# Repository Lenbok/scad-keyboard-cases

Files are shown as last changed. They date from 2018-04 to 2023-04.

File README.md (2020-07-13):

# OpenSCAD Mechanical Keyboard Cases

This repository uses OpenSCAD to make 3D-printable keyboard
cases. Initially this was simple modifications to an existing case for
the [Redox](https://github.com/mattdibi/redox-keyboard) handwire
keyboard, but now also provides the possibility to make a new case
generated in OpenSCAD from scratch.

When cloning, you need to make sure you get the submodules, e.g.:

    git clone --recurse-submodules https://github.com/Lenbok/scad-keyboard-cases.git

## Modified Version Of The Redox Case

Have a look in [redox-rev0-mod](redox-rev0-mod) for my modification of
the original handwire Redox case.

## Keyboard Cases From Scratch

I then wanted to design a new case for the Redox that was inspired both
by the Redox Rev1 case and the Iris, and I thought it would be nice to
start with the layout from the [Keyboard Layout
Editor](http://www.keyboard-layout-editor.com/) JSON file (in this way
it could be extended to other keyboards). Existing tools I had found for
going from KLE JSON to OpenSCAD didn't work for split keyboards where
some keys are rotated, so an updated tool is provided here that seems to
work on the split keyboards I have tried.

Examples: [Redox](redox-rev0b) and [Corne](crkbd) keyboards.

If you have another KLE JSON file you want to convert, run the included
`jsonPositions.py` which spits out the key layout to a minimal OpenSCAD
data structure along with some data access functions. E.g:

    python3 jsonPositions.py -v redox_layout <redox-rev0b/redox-layout.json >redox-rev0b/redox-layout.scad

Where `-v redox_layout` designates the OpenSCAD variable name used to
contain the layout data in the generated file.  Then make a top level
OpenSCAD that includes this along with `keyboard_case.scad`, e.g.:

    include <redox-rev0b/redox-layout.scad>
    include <keyboard_case.scad>

Then to make a case, you mostly just need to define a polygon describing the
outer boundary of your desired case, a set of points for where to put
case screw holes, and optional positions for tenting supports, and call
the `top_case` and/or `bottom_case` modules. 

See some of the cases here for examples:

Redox:

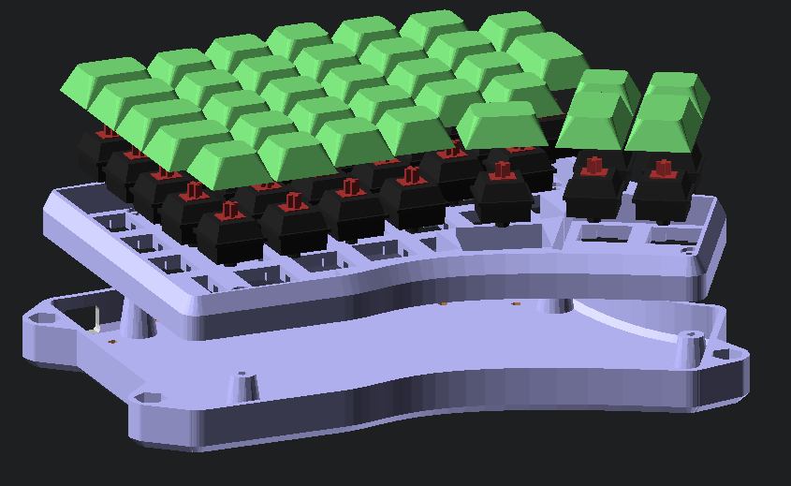
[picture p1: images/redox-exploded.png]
redox exploded


CRKBD (main shell is top half):

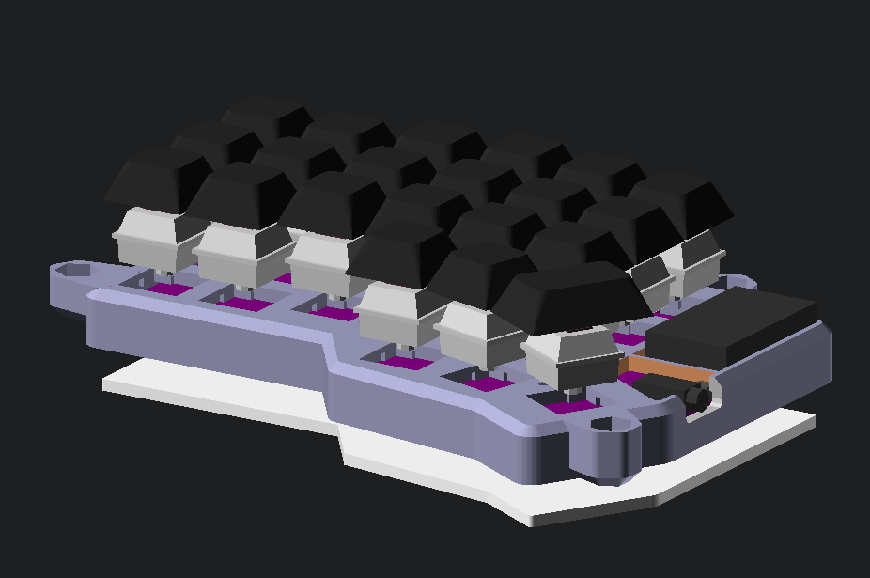
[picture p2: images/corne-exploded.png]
crkbd


CRKBD "alternate" (hi-profile, main shell is lower half):

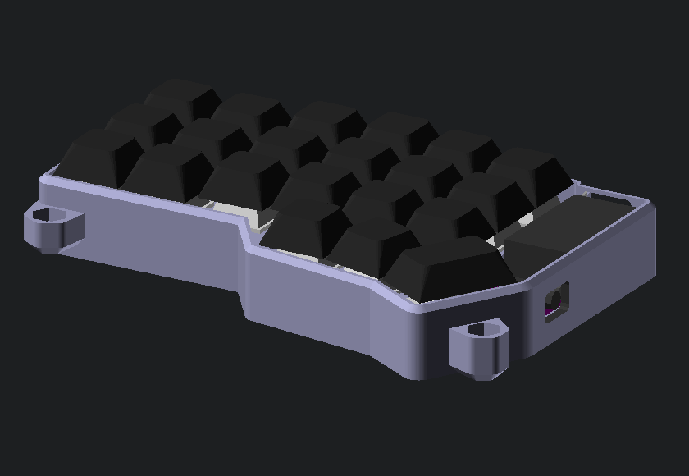
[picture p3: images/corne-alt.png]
crkbd alternate


CRKBD "minimal" (here using bottom mount mcu and reset for low profile):

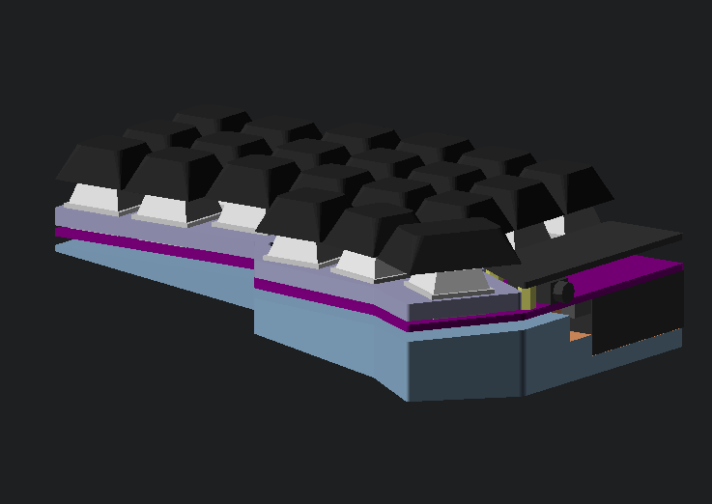
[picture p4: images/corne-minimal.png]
crkbd minimal


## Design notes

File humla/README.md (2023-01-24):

## Humla keyboard cases

In this folder are a couple of different cases for the
[Humla](https://github.com/jimmerricks/humla) keyboard.

### Simple bumper

Just a straight bumper-style case:

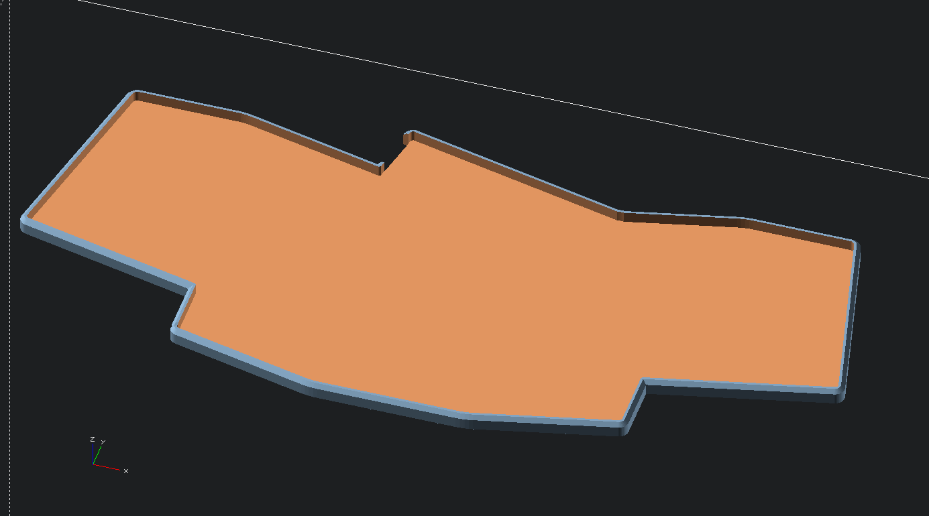
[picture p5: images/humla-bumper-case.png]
humla bumper


At the moment, the case does not attach with screws, it just fits snugly.

### "Laptop Adaptor" case

Since one use case when building this keyboard was as an comfortable
alternative to the keyboard built-in to my work laptop (a HP ZBook Firefly), this
case is an adaptor that lets the humla sit over the top of the laptop
keyboard. Recesses corresponding to the laptop keys keep the humla positioned.

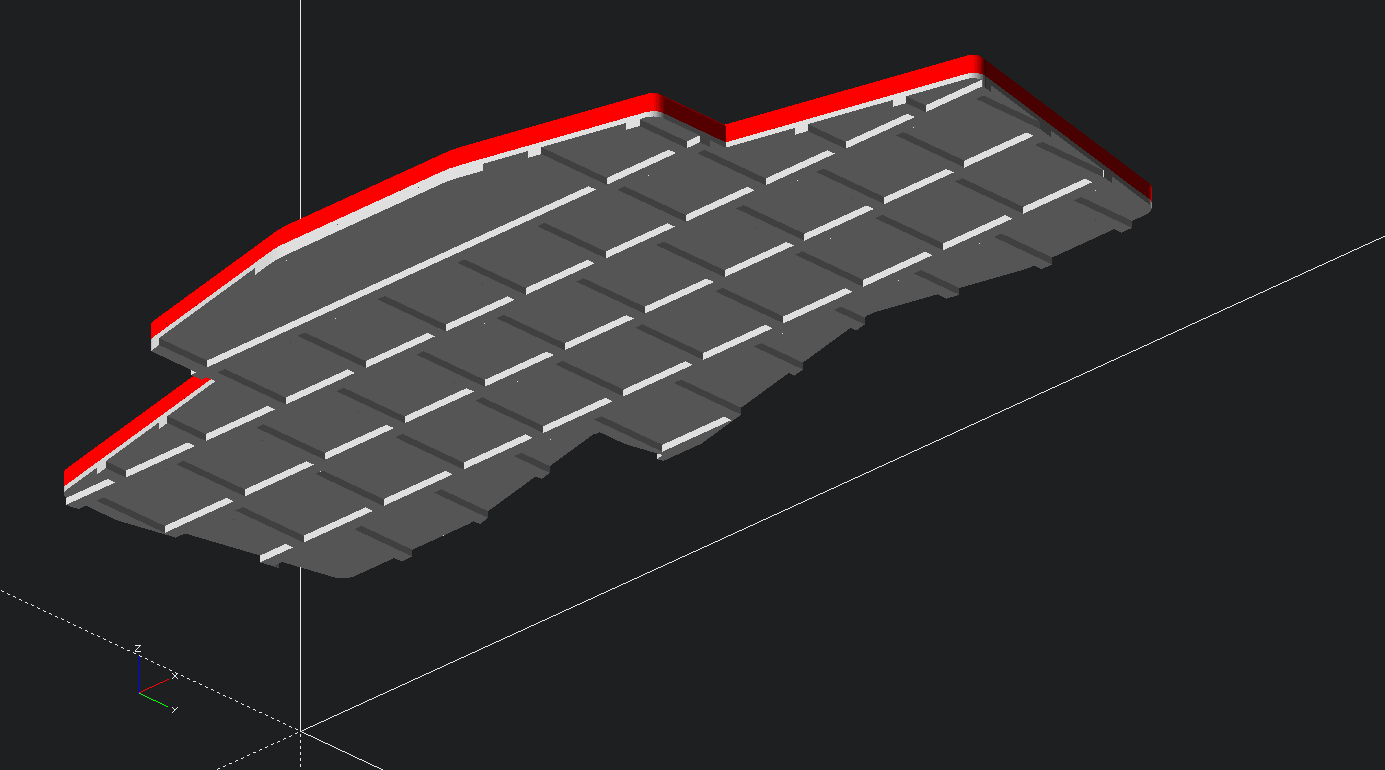
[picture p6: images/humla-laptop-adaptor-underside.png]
humla laptop adaptor case


To make this case, print one adaptor plate and one bumper plate and glue them
together.

It would be easy to alter this for a different laptop by creating a KLE layout
containing the positions and sizes of your laptop keyboard, and running the
converter in this repo to convert that into the OpenSCAD data structure
required.

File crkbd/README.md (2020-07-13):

## CRKBD keyboard cases from scratch

In this folder are a couple of different cases for the
[Corne](https://github.com/foostan/crkbd) keyboard.

### Default case (AKA first version)

This has a top plate with tenting supports attached. The bottom plate
could be 3D printed in transparent plastic so that underglow shows
through (it should also be compatible with the laser cut acrylic bottom
plate).

crkbd exploded

The top part has a couple of struts across where the OLED screen goes
that are purely to assist with keeping the edge attached during
printing, and these should be cut out after printing. The outermost
tenting mounts are raised compared to the inner ones, this is to allow
the outer sides to sit closer to the desk.

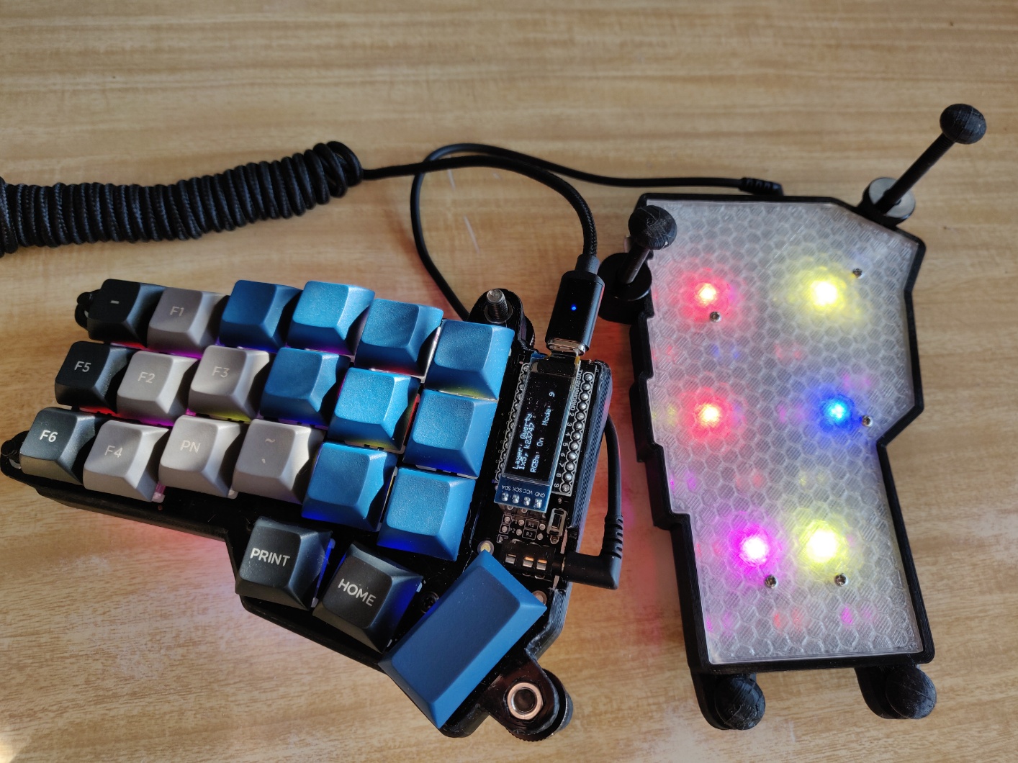
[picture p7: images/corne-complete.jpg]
corne complete


I've also designed a simple carrier that each half of the keyboard slots
into, and which has a wee compartment into which you can put the TRRS
cable and tenting legs during transport.

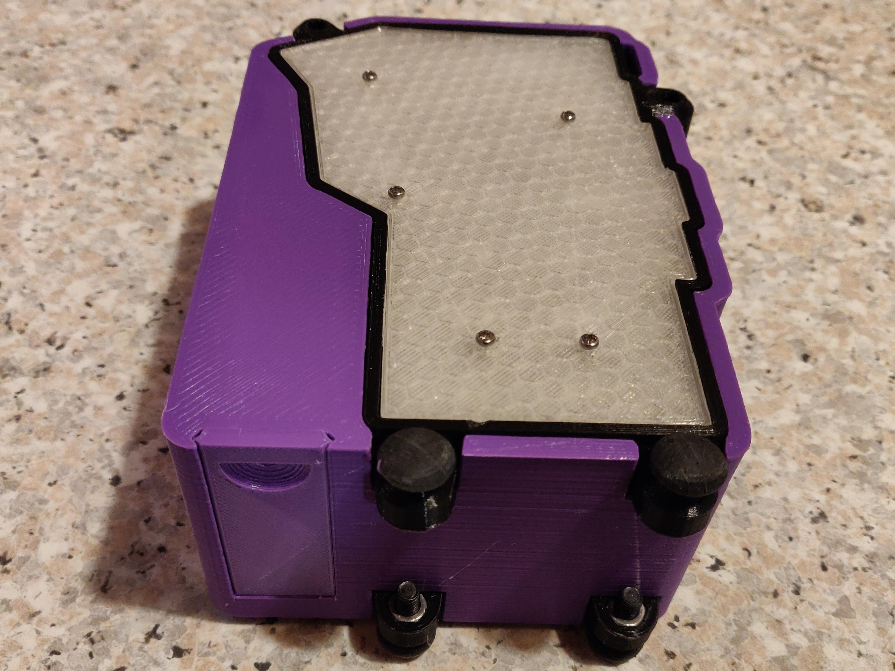
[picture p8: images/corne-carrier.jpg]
corne carrier


### "Alternate" case

This version of the case has a simple printed top plate (essentially as
thick as possible for strength - you may need to clip diode legs etc),
and the bottom half contains the tenting etc. This version is "high
profile" where the sides come up to the bottom of the keycaps:

crkbd alternate

The tenting positions are differently arranged, but you can use the
definitions from the default case if you prefer those.

If you want this case to be compatible with RGB underglow lighting, it's
best to print the first few mm in transparent filament before swapping
to the color you want for the bulk of the case.

Mine is using a top mounted
[nRFMicro](https://github.com/joric/nrfmicro) for bluetooth, and has a
separate LiPo battery bay.

Here are the default and alternate cases:

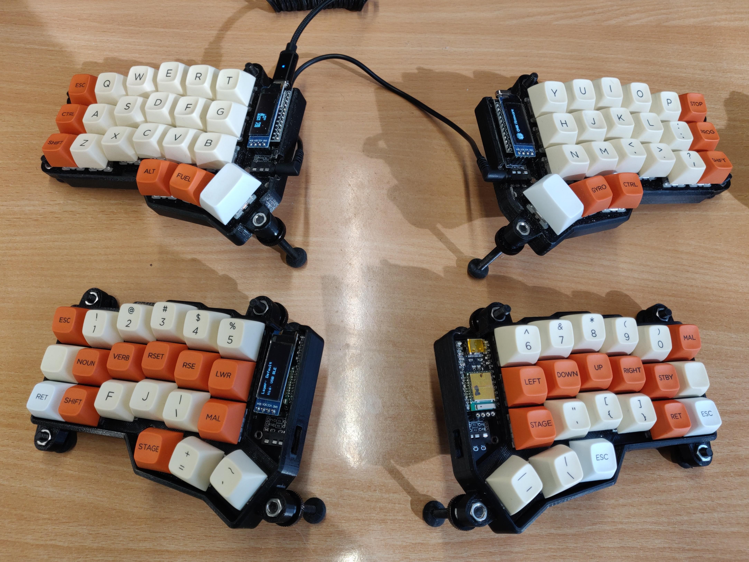
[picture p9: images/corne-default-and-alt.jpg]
crkbd default and alt


### "Minimal" case

This version of the case has the same simple top plate as the alternate
case, and the bottom is pretty much a wedge shape so we have the minimal
footprint. You can configure whether you want the MCU and/or the reset
switch mounted under the PCB (this allows the OLED to sit close to the
PCB).

crkbd minimal

Mine is using a bottom mounted
[nRFMicro](https://github.com/joric/nrfmicro) which also straddles a
small LiPo, making it a nice compact bluetooth keyboard.

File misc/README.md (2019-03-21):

# Misc Supporting Files

The tenting solution I've been using has been based around M5 coach
bolts, and I've been using 3D printed molds to cast
[Oogoo](https://www.instructables.com/id/How-To-Make-Your-Own-Sugru-Substitute/)
around the heads of the bolts to give them rubber feet.

Rubber Feet Enabled Bolts

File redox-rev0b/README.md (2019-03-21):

## Redox Keyboard Case From Scratch

I wanted to design a new case for the Redox that was inspired both
by the Redox Rev1 case and the Iris, and I thought it would be nice to
start with the layout from the [Keyboard Layout
Editor](http://www.keyboard-layout-editor.com/) JSON file (in this way
it could be extended to other keyboards). Existing tools I had found for
going from KLE JSON to OpenSCAD didn't work for split keyboards where
some keys are rotated, so an updated tool is provided here that seems to
work on the split keyboards I have tried.

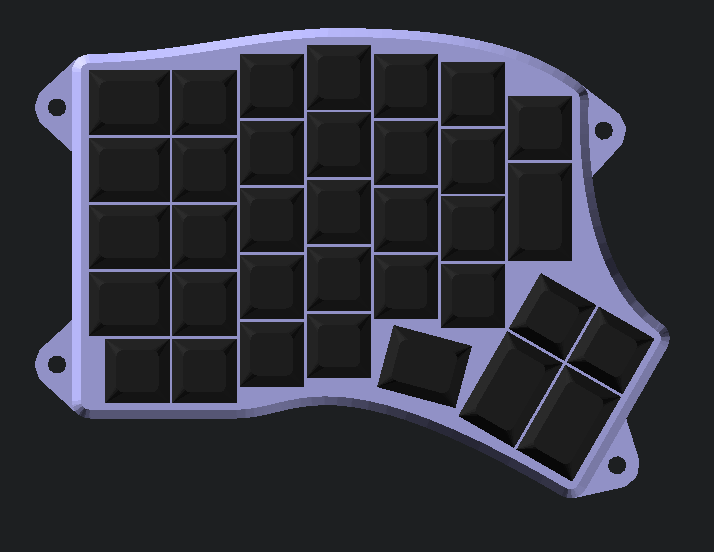
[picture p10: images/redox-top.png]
redox-top


redox-exploded

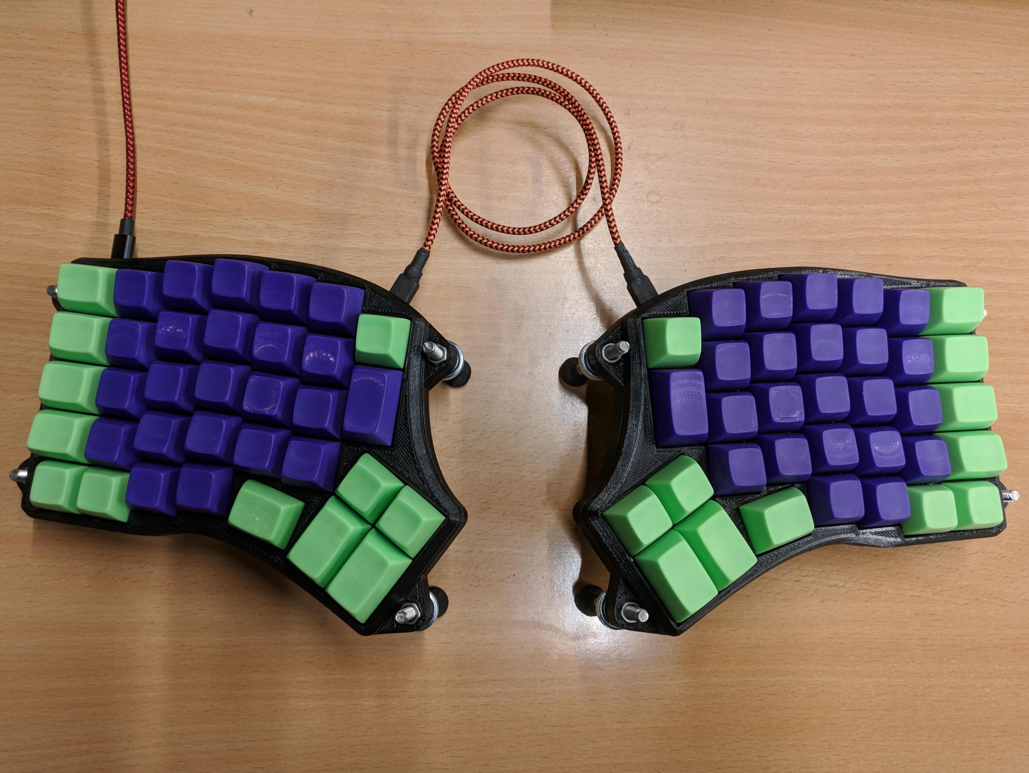
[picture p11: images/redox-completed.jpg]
redox-completed

[album here](https://imgur.com/a/eEi0gJ1)

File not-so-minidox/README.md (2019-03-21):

## Not-so-minidox Keyboard Case From Scratch

This is initial work on a case for the
[Not-so-minidox](https://www.reddit.com/r/MechanicalKeyboards/comments/8j8k1i/the_not_so_minidox_handwire/)
keyboard, but I've since decided to build a Corne keyboard instead.

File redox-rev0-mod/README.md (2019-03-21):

# A modified case for the Redox keyboard

The [Redox](https://github.com/mattdibi/redox-keyboard) keyboard is a DIY mechanical 
keyboard by MattDB. It is sort of a cross between an 
[Iris](https://keeb.io/products/iris-keyboard-split-ergonomic-keyboard) and an 
[Ergodox](https://ergodox-ez.com/).

This repository uses OpenSCAD to make some modifications to the original STL to add
tenting etc.

This was my first modification of the original handwire redox case. Load the
`redox-body-mod.scad` into OpenSCAD, make any changes, and render the
modified STL.

This one has been built by a few people, e.g: [by me](https://imgur.com/a/DzFYMhc), 
and [a coworker](https://www.thingiverse.com/make:486818)

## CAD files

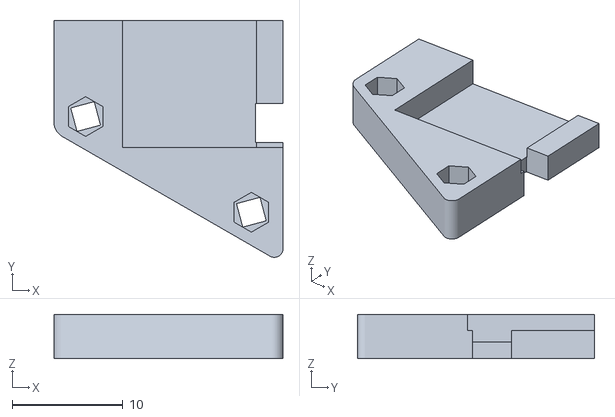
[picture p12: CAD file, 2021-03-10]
crkbd/stls/crkbd-case-encoder-mount.stl
20.7 x 21.4 x 4.00

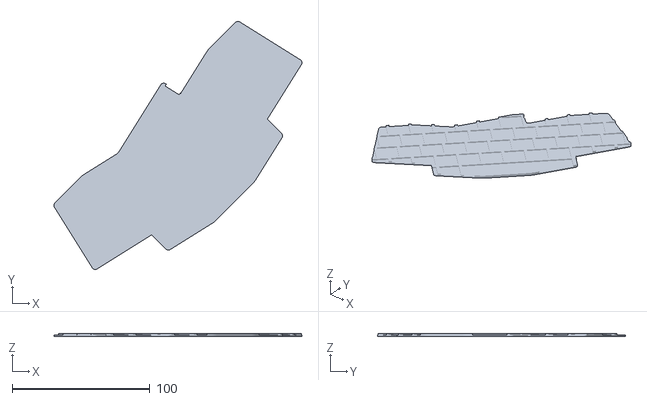
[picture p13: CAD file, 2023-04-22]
humla/stl/humla-laptop-adaptor-case-bottom.stl
180.2 x 180.2 x 2.29

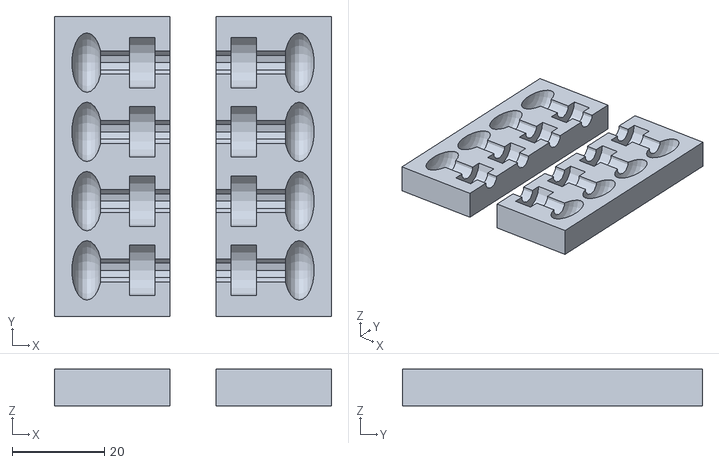
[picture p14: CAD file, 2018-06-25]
misc/stls/Foot_Mold.stl
60.0 x 65.0 x 8.00

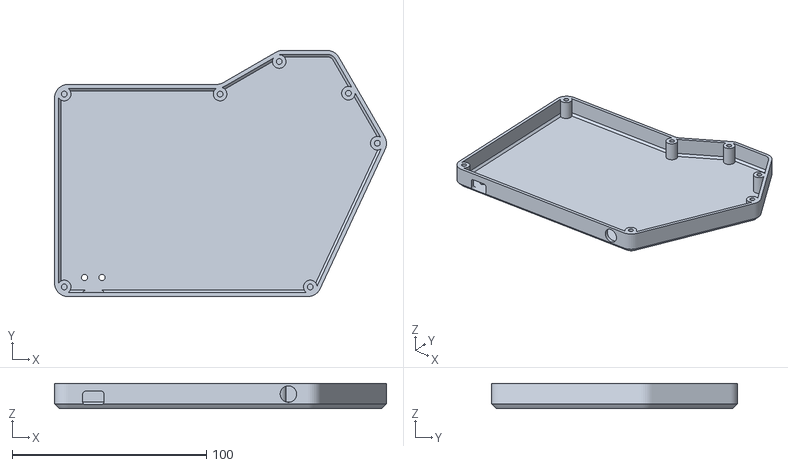
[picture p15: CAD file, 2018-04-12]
redox-rev0-mod/orig/BottomR.stl
171.1 x 126.9 x 13.0

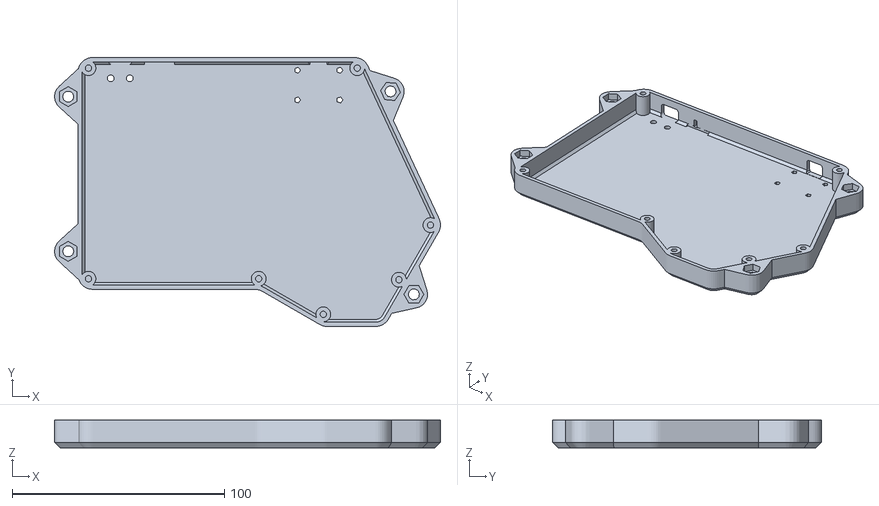
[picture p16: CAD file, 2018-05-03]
redox-rev0-mod/stls/Tented_BottomL.stl
182.1 x 126.9 x 13.0

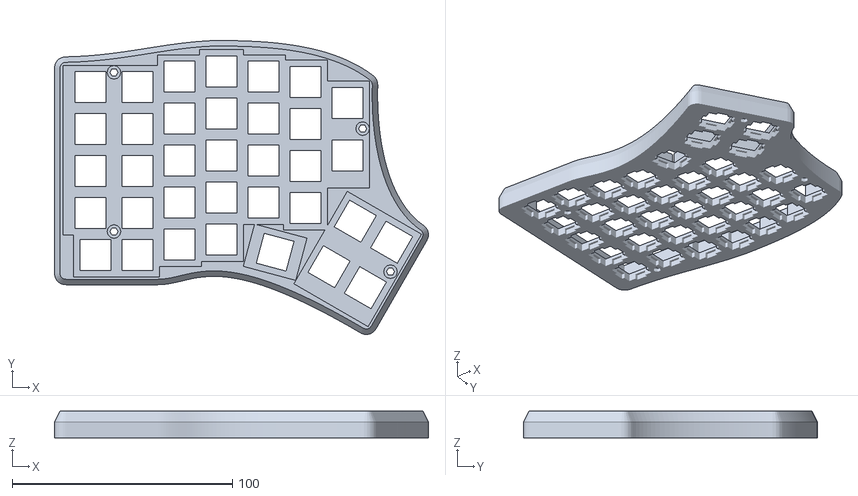
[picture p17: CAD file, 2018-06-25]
redox-rev0b/stls/redox-rev0b-hightop.stl
169.6 x 133.4 x 12.2

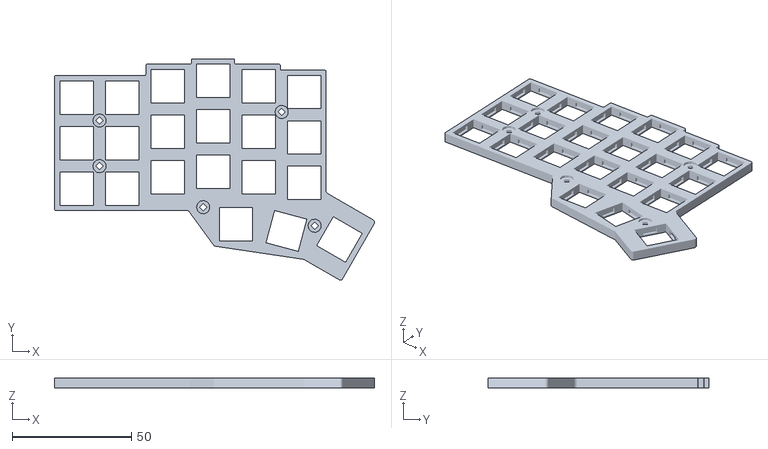
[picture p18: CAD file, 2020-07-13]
crkbd/stls/crkbd-case-minimal-top.stl
134.1 x 92.8 x 4.00

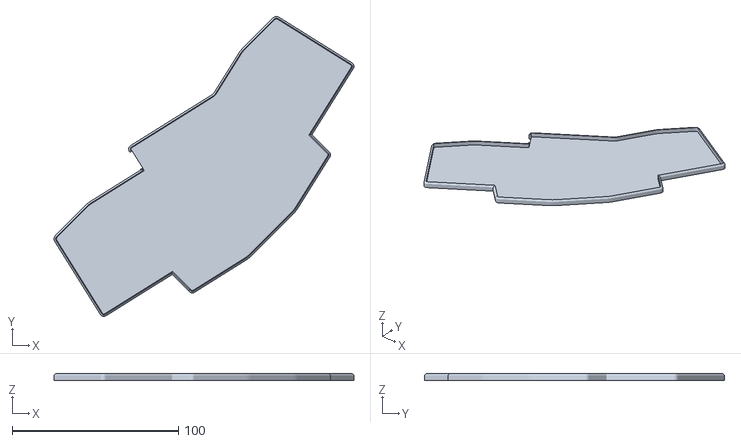
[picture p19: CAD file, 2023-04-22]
humla/stl/humla-bumper-case.stl
180.2 x 180.2 x 4.00

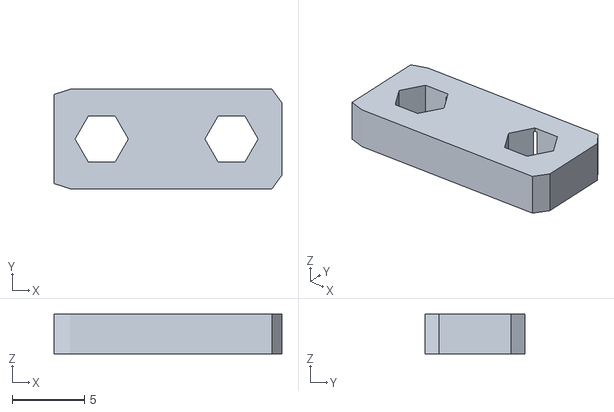
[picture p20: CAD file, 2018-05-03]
misc/stls/Micro_USB_Spacer.stl
15.8 x 6.90 x 2.75

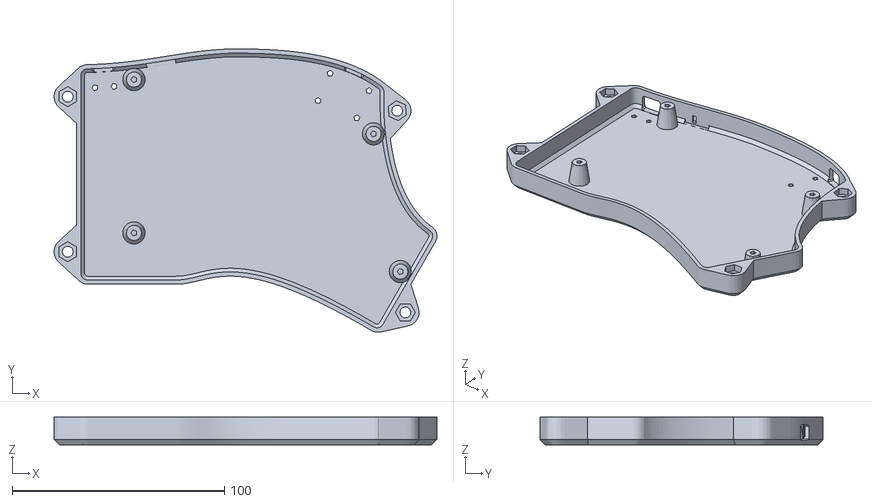
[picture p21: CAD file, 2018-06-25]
redox-rev0b/stls/redox-rev0b-bottom.stl
180.3 x 133.4 x 13.0

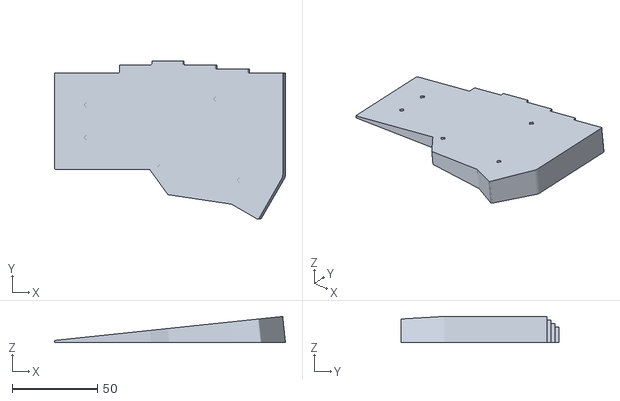
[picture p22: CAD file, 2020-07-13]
crkbd/stls/crkbd-case-minimal-bottom.stl
135.5 x 92.8 x 15.3

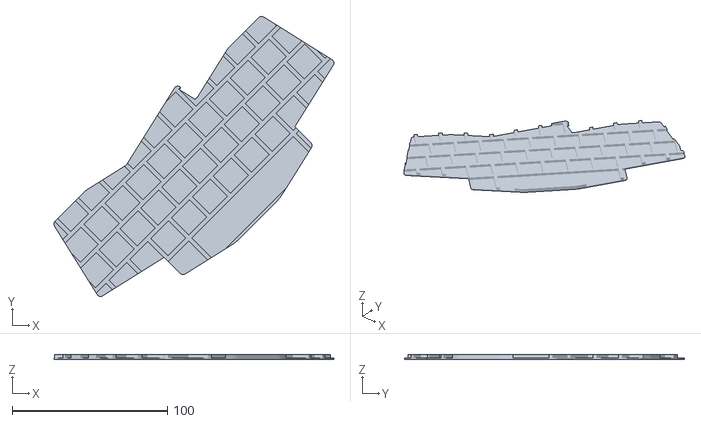
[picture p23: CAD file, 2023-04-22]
humla/stl/humla-macbook-adaptor-case-bottom.stl
180.2 x 180.2 x 2.99

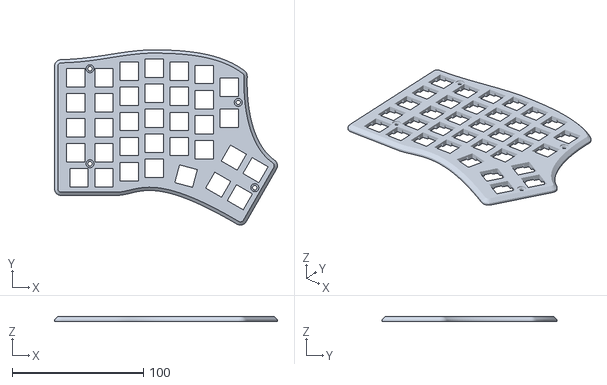
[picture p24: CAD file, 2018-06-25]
redox-rev0b/stls/redox-rev0b-lowtop.stl
169.6 x 133.4 x 4.00

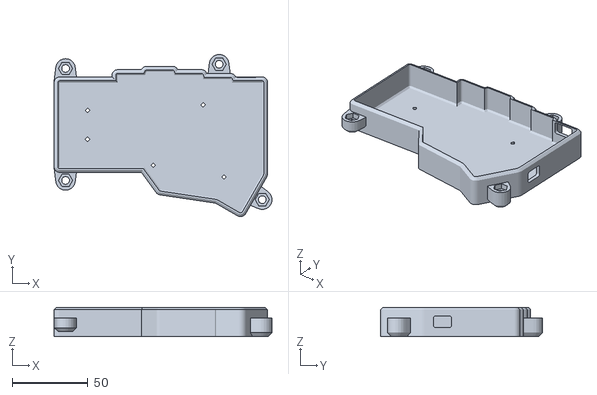
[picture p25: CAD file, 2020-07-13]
crkbd/stls/crkbd-case-alt-bottom.stl
144.0 x 107.1 x 19.2

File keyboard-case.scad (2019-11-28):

unit = 19.05;            // Unit size of spacing between keys

cherry_plate_width = 14; // Width of hole in plate for key insertion. Adjust if needed

plate_thickness = 4;   // Fairly thick for strength, ideally print this section with high infill
top_case_raised_height = 7.2 + 1; // Distance between plate and bottom of keycap plus a little extra, for raised top case
bottom_case_height = 13;  // Enough room to house electonics
wall_thickness = 2;     // Sides and bottom of case
depth_offset = 0;       // How much of side wall to include below top plate

// Case screw sizes
standoff_rad = 7 / 2;
screw_rad = 3.2 / 2;
screw_head_rad = 6 / 2;
screw_length = 8;
bottom_screws = false; // Default is to screw down from the top

themes = [
    //    case,    keycap, keyswitch,  keystem
    ["#101010", "#130044", "#222222", "#aa3333"],
    ["#180054", "#73d373", "#222222", "#aa3333"],
    ["#bbbbff", "#73d373", "#222222", "#aa3333"],
    ["#9999bb", "#252525", "#cccccc", "#553333"],
    ];
theme = 3;
case_color = themes[theme].x;
keycap_color = themes[theme].y;
keyswitch_color = themes[theme].z;
keystem_color = themes[theme][3];

// Create a hole where a switch can be inserted. The top of the hole is at 0
cherry_clip_recess_z = 1.3; // How far below the top the recess begins
cherry_clip_recess_width = 6; // How much of the side is taken up by the recess
cherry_clip_recess_depth = 1.0; // How far in does the clip go
cherry_clip_recess_height = 4.0; // How far down clip recess go
module switch_hole(size, depth = 5) {
    translate([0, 0, -depth]) {
        linear_extrude(height = depth + 0.01, center = false, convexity = 3)
            square([cherry_plate_width, cherry_plate_width], center = true);
        translate([0, 0, depth - cherry_clip_recess_z - cherry_clip_recess_height]) linear_extrude(height = cherry_clip_recess_height, center = false, convexity = 3)
            for (r = [0, 90])
                rotate([0, 0, r])
                    square([cherry_plate_width + 2 * cherry_clip_recess_depth, cherry_clip_recess_width], center = true);
    }
}

// A keyswitch for preview purposes
cherry_switch_width = 14;
cherry_switch_depth = 5.2;
module cherry_keyswitch() {
    color(keystem_color) translate([0, 0, 5]) {
        translate([0, 0, 0.5]) cube([7, 5.7, 1], center = true);
        translate([0, 0, 1 + 1.8])
            for (r = [0, 90])
                rotate([0, 0, r])
                cube([4.0, 1.2, 3.6], center = true);
    }
    color(keyswitch_color) {
        hull() {
            translate([0, 0, 0.99]) linear_extrude(height = 0.01, center = false, convexity = 3) 
                square([14, 14], center = true);
            translate([0, 0, 5.6]) linear_extrude(height = 0.01, center = false, convexity = 3) 
                square([11, 11], center = true);
        }
        translate([0, 0, 0.5]) cube([15.6, 15.6, 1], center = true);
        translate([0, 0, -8.3]) cylinder(r = 3.8 / 2, h = 5, $fn = 8);
        hull() {
            linear_extrude(height = 0.01, center = false, convexity = 3) 
                square([cherry_switch_width, cherry_switch_width], center = true);
            translate([0, 0, -cherry_switch_depth]) linear_extrude(height = 0.01, center = false, convexity = 3) 
                square([cherry_switch_width-0.5, cherry_switch_width-0.5], center = true);
        }
    }
}

// Something roughly DSA-ish for preview purposes
keycap_depth_offset = 7.2;  // Distance from bottom of keycap to top of plate.
module simple_keycap(size) {
    color(keycap_color) translate([0, 0, keycap_depth_offset]) hull() {
        linear_extrude(height = 0.01, center = false, convexity = 3)
            offset(delta = -0.4, chamfer = false) square(size * unit, center = true);
        translate([0, 0, 8]) linear_extrude(height = 0.01, center = false, convexity = 3)
            offset(r = 2, $fn = 16) offset(delta = -5.5) square(size * unit, center = true);
    }
}

// Negative space for a keycap for raised top cases
module keycap_hole(size, depth = top_case_raised_height) {
    linear_extrude(height = depth + 1, center = false, convexity = 3)
        offset(delta = 0.4) square(size * unit, center = true);
}

// Negative space for a key switch plus keycap
module case_switch_hole(size) {
    keycap_hole(size);
    switch_hole(size);
}

// For subtracting a hole in the bottom case for a microswitch
module reset_microswitch(hole = true) {
    color("#202020") cube([14, 6, 6], center = false);
    color("red") translate([4, 0.01, 1])  cube([2, hole ? 10 : 7, 4], center = false);
}

// Typical mini USB breakout boards from e.g. Aliexpress
mini_usb_screw_dia = 3.0;
mini_usb_screw_rad = (mini_usb_screw_dia - 0.6) / 2; // Smaller than M3 to tap into
mini_usb_screw_sep = 20;
mini_usb_hole_height = 7.5;
module mini_usb_hole(hole = true) {
    color("green") translate([0, -11, pcb_thickness/2]) cube([25.5, 19.5, pcb_thickness], center = true);
    if (hole) {
        translate([0, 0, mini_usb_hole_height/2])  rotate([90, 0, 0]) roundedcube([10, mini_usb_hole_height, 10], r=1.5, center=true, $fs=1);
    }
    color("silver") translate([0, -5, mini_usb_hole_height/2])  rotate([90, 0, 0]) cube([7.6, 3.7, 9.2], center=true, $fs=1);
    for (i = [-1,1], j = [0, 14]) {
        translate([i*mini_usb_screw_sep/2, -4-j, -5]) polyhole(r=mini_usb_screw_rad, h=10);
    }
}

// Typical micro USB breakout boards from e.g. Aliexpress
micro_usb_screw_dia = 3.0;
micro_usb_screw_rad = (micro_usb_screw_dia - 0.6) / 2; // Smaller than M3 to tap into
micro_usb_screw_sep = 9;
micro_usb_hole_width = 11;
micro_usb_hole_height = 7.5;
micro_usb_socket_height = 2.5;
pcb_thickness = 2;
module micro_usb_hole(hole = true) {
    color("green") translate([0, -8, pcb_thickness/2]) cube([14, 14, pcb_thickness], center = true);
    color("silver") {
        if (hole) {
            translate([0, 1, pcb_thickness+micro_usb_socket_height/2]) rotate([90, 0, 0]) roundedcube([micro_usb_hole_width, micro_usb_hole_height, 10], r=1.5, center=true, $fs=1);
        }
        translate([0, -3, pcb_thickness + micro_usb_socket_height / 2]) rotate([90, 0, 0]) cube([7.5, micro_usb_socket_height, 7], center = true, $fs = 1);
    }
    for (i = [-1,1]) {
        translate([i * micro_usb_screw_sep/2, -8, -5]) polyhole(r = micro_usb_screw_rad, h = 15);
    }
}

// You can use this for things that don't need to vary each child according to the key (e.g. size)
module key_positions(keys) {
    // Mirror because KLE has Y axis reversed
    mirror([0, 1, 0]) for (key = keys)
        position_key(key, unit = unit)
            children();
}

module key_holes(keys, type = "both") {
    //echo("Number of keys:",len(keys));
    // Mirror because KLE has Y axis reversed
    mirror([0, 1, 0]) for (key = keys) {
        position_key(key, unit = unit)
            if (type == "both") {
                case_switch_hole(key_size(key));
            } else if (type == "plate") {
                switch_hole(key_size(key));
            } else if (type == "switch") {
                cherry_keyswitch();
            } else if (type == "keycap") {
                simple_keycap(key_size(key));
            }
    }
}

module screw_positions(screws) {
    for (screw = screws) translate(screw) children();
}

module screw_holes(screws, screw_depth = 8, screw_head_depth = plate_thickness + top_case_raised_height) {
    screw_positions(screws) {
        mirror([0, 0, 1]) translate([0, 0, -screw_head_depth]) bolthole(r1=screw_head_rad, r2=screw_rad, h1=screw_head_depth, h2=screw_depth);
    }
}


// M5 bolt tenting
tent_bolt_rad = 5 / 2;
tent_nut_rad = 9.4 / 2;
tent_nut_height = 3.5;
tent_attachment_width = 35;
module tent_support(position, angle, height = bottom_case_height, lift = 0) {
    base_chamfer = 2.5;
    off = apothem(tent_nut_rad, 6) + 0.5;
    translate([position.x, position.y, lift]) rotate([0, 0, angle]) {
        difference() {
            chamfer_extrude(height = height, chamfer = base_chamfer, faces = [true, false]) {
                hull() {
                    translate([-6.5, 0]) square([0.1, tent_attachment_width], center = true);
                    translate([off, 0]) circle(r = tent_bolt_rad + base_chamfer + 1.5);
                }
            }
            //translate([-10,-20, -0.1]) cube([10-base_chamfer, 40, bottom_case_height+1], center=false);
            // Screw hole
            translate([off, 0, -0.1]) polyhole(r=tent_bolt_rad, h=height+1);
            // Nut hole
            translate([off, 0, height-tent_nut_height]) rotate([0, 0, 60/2]) cylinder(r=tent_nut_rad, h=tent_nut_height+0.1, $fn=6);
        }
    }
}
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

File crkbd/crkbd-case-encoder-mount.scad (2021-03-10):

///////////////////////////////////////////////////
// Small plate to mount an encoder where the TRRS jack normally goes,
// for use when the crkbd makes use of a bluetooth MCU (nRFmicro,
// nice!nano, etc). Assumes the reset switch is bottom mounted.
///////////////////////////////////////////////////

include <../keyboard-case.scad>
include <crkbd-common.scad>

theme = 3;
top_mount_mcu = false;
top_mount_reset = false;
window_z = top_mount_mcu ? 13 : 6;

$fa = 1;
$fs = $preview ? 8 : 2;

encoder_base_size = [12.1, 11.5, 1];
encoder_base_size2 = [15.1, 11.5, 1.5];

module encoder_base_cutout() {
    cube(encoder_base_size + [0, 0, 0.01], center = false);
    translate([0, 0, encoder_base_size.z]) cube(encoder_base_size2, center = false);
}

module crkbd_encoder_mount() {
    mount_thickness = 1.5;
    mount_y = 22;
    standoff_rad = 1.8; // 1.8 fits brass standoffs; 2.6 fits nylon standoffs
    encoder_position_tweak = [1.9, 0, 0.01];
    difference() {
        color("#333333") translate([0, 0, crkbd_pcb.z]) linear_extrude(height = mount_thickness + encoder_base_size.z + encoder_base_size2.z, convexity = 3)
            // Create 2d profile first
            difference() {
            crkbd_left_top_window();

            translate(-crkbd_first_offset) translate([crkbd_pcb.x, -crkbd_window_size.y]) {

                // Truncate the window
                translate([-crkbd_window_size.x - 0.01, mount_y]) square([crkbd_window_size.x + 0.02, crkbd_window_size.y], center = false);

                // Cutout for wires to matrix
                translate([-2.5, 11]) square([5, 3.5], center = false);

                // Screw holes
                translate([-crkbd_window_size.x / 2, 9])
                    for (i = [-30, 150])
                        rotate([0, 0, i]) translate([crkbd_window_size.x / 2 - 1.7, 0])
                            polyhole2d(r = 1.1);
            }
        }
        translate([0, 0, crkbd_pcb.z]) translate(-crkbd_first_offset) translate([crkbd_pcb.x, -crkbd_window_size.y]) {
            // Cut out encoder footprint
            translate([-encoder_base_size.x/2 - crkbd_window_size.x/2, mount_y - encoder_base_size.y + 0.01, mount_thickness + 0.01])
                translate(encoder_position_tweak) encoder_base_cutout();
            // And a hole to make room for one of the reset switch pads
            translate([-1.6, 18.6, -0.01]) cylinder(r = 1.1, h = 1.4, center = false);
        }

        // Standoff recesses
        color("#cccc66") translate(-crkbd_first_offset)
            translate([crkbd_pcb.x - crkbd_window_size.x / 2, 9 - crkbd_window_size.y, crkbd_pcb.z + mount_thickness])
            for (i = [-30, 150])
                rotate([0, 0, i]) translate([crkbd_window_size.x / 2 - 1.7, 0, 0])
                    cylinder(r = standoff_rad, h = window_z, $fn = 6);
    }
}

part = "encoder-plate";
//part = "assembly";
explode = 0;
depressed = false;

if (part == "encoder-plate") {
    translate(crkbd_center_offset) crkbd_encoder_mount();
    //%translate([0, 0, plate_thickness + -7 * explode]) key_holes(left_keys, "keycap");
} else if (part == "assembly") difference(convexity=10) {
    union() {
        //rotate([0, -tent_angle, 0])
        translate([-80, 60, plate_thickness]) {
            %translate([0, 0, plate_thickness - (depressed ? 4 : 0) + 30 * explode]) key_holes(left_keys, "keycap");
            %translate([0, 0, plate_thickness + 20 * explode]) key_holes(left_keys, "switch");

            %translate([0, 0, -2.5 - 5 * explode]) crkbd_pcb_assembly(top_mount_mcu = top_mount_mcu, top_mount_reset = top_mount_reset, top_mount_trrs = false, window_z = window_z);

            translate([0, 0, -2.5 - 5 * explode]) crkbd_encoder_mount();

        }
    }
}


// Requires my utility functions in your OpenSCAD lib or as local submodule
// https://github.com/Lenbok/scad-lenbok-utils.git
use<../Lenbok_Utils/utils.scad>

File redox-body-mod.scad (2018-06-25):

$fa=1;
$fs=5;
$fs=2;    // Uncomment for final render

base_height = 13;
base_chamfer = 2.5;
wall_thickness = 2.0004;

usb_interconnect = 1; // 0 = keep existing TRRS interconnect hole, 1 = mini-usb interconnect

tent_positions = [
    // [X, Y, Angle]
    [85.5, 45.0, 0],
    [85.5, -28, 0],
    [-57.8, 45.5, 155],
    [-69, -46, -150],
    ];

// M5 bolt tenting
boltRad = 5 / 2;
nutRad = 9.4 / 2;
nutHeight = 3.5;
module tent_support(position) {
    off = apothem(nutRad, 6)+0.5;
    lift = 0;
    height = base_height - lift;
    translate([position[0], position[1], lift]) rotate([0, 0, position[2]]) {
        difference() {
            chamfer_extrude(height=height, chamfer=base_chamfer, faces = [true, false]) {
                hull() {
                    translate([-5,0]) square([0.1, 35], center=true);
                    translate([off, 0]) circle(r=boltRad+base_chamfer+1.5);
                }
            }
            translate([-10,-20, -0.1]) cube([10-base_chamfer, 40, base_chamfer+1], center=false);
            translate([-10,-20, base_chamfer]) cube([10-wall_thickness+0.1, 40, base_height+1], center=false);
            translate([off, 0, -0.1]) polyhole(r=boltRad, h=height+1);
            // Nut hole
            translate([off, 0, height-nutHeight]) rotate([0, 0, 60/2]) cylinder(r=nutRad, h=nutHeight+0.1, $fn=6);
        }
    }
}

mini_usb_screw_rad = 2.4 / 2; // Smaller than M3 to tap into
mini_usb_screw_sep = 20;
mini_usb_hole_height = 7.5;
module mini_usb_hole() {
    translate([0, 0, mini_usb_hole_height/2])  rotate([90, 0, 0]) roundedcube([10, mini_usb_hole_height, 10], r=1.5, center=true, $fs=1);
    for (i = [-1,1], j = [0, 14]) {
        translate([i*mini_usb_screw_sep/2, -4-j, -5]) polyhole(r=mini_usb_screw_rad, h=10);
    }
}

micro_usb_screw_dia = 3.0;
micro_usb_screw_rad = (micro_usb_screw_dia - 0.6) / 2; // Smaller than M3 to tap into
micro_usb_screw_sep = 9;
micro_usb_hole_height = 7.5;
micro_usb_socket_height = 2.5;
pcb_thickness = 2;
module micro_usb_hole() {
    translate([0, 1, micro_usb_hole_height/2]) rotate([90, 0, 0]) roundedcube([11, micro_usb_hole_height, 10], r=1.5, center=true, $fs=1);
    translate([0, -1.5, pcb_thickness + micro_usb_socket_height / 2]) rotate([90, 0, 0]) cube([7.5, micro_usb_socket_height, 10], r = 1.5, center = true, $fs = 1);
    for (i = [-1,1]) {
        translate([i * micro_usb_screw_sep/2, -8, -5]) polyhole(r = micro_usb_screw_rad, h=15);
    }
}

// Print a couple of these to prevent heads of the mini-usb mounting screws from
// hitting the mini-usb socket
module micro_usb_bracket() {
    height = micro_usb_socket_height + 0.25; // One layer above
    difference() {
        translate([0, 0, height/2])  roundedcube([micro_usb_screw_sep + 7, 7, height], center = true);
        translate([0, 8, -pcb_thickness - 0.01]) micro_usb_hole();
        for (i = [-1,1]) {
            translate([i * micro_usb_screw_sep/2, 0, 0]) polyhole(r = (micro_usb_screw_dia + 0.2) / 2, h = 15, center = true);
        }
    }
}

// Make a mold for making an oogoo foot around the M5 nut heads.
module foot_negative() {
    rotate([0, 90, 0]) {
        // Nut trap to stop the bolt from being pushed out. Two half height nuts.
        translate([0, 0, -1]) cylinder(r = nutRad + 0.75, h = 5.5, center = true, $fn=16);
        // actual bolt shaft
        polyhole(r = boltRad, h = 20, center = true);
        // show actual bolt head shape
        translate([0, 0, 10]) cylinder(r1 = 5, r2 = 2.5, h = 2.7, center = false);
        // This is the rubber around the head
        translate([0, 0, 11]) {
            scale([1, 1, 0.5])  sphere(r = 6.5);
        } 
    }
}

module foot_mold() {
    height = 8;
    for (m = [0, 1])
        mirror([m, 0, 0])
            translate([5, 0, 0])
            difference() {
            translate([0, -10, 0])  cube([25, 65, height], center = false);
            for (i = [0:3]) {
          #      translate([7, i*15, height]) foot_negative();
            }
    }
}

module modified_base() {
    difference() {
        union() {
            rotate([0,0,180]) import("orig/BottomR.stl");
            if (usb_interconnect) {
                // Fill in TRRS hole, since we'll do something different
                translate([-42, 61.426, base_chamfer]) cube([20, wall_thickness, base_height - base_chamfer - 0.1]);
            }
            for(i = [0:len(tent_positions)-1]) {
                tent_support(tent_positions[i]);
            }
        }
        if (usb_interconnect) {
            translate([-28, 61.426, wall_thickness]) mini_usb_hole();
            //translate([65.5, 61.426, wall_thickness]) micro_usb_hole();
        }
        // Hole to access reset microswitch
        #translate([40, 55.38, wall_thickness]) {
            cube([14, 6, 6], center = false);
            translate([8, 0, 1])  cube([2, 10, 4], center = false);
        }
    }
}

//mirror([1, 0, 0])
modified_base();

//micro_usb_bracket();

//foot_mold();

// Requires my utility functions in your OpenSCAD lib or as local submodule
// https://github.com/Lenbok/scad-lenbok-utils.git
use<Lenbok_Utils/utils.scad>

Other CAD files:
crkbd/stls/crkbd-case-carrier.stl
crkbd/stls/crkbd-case-carrier-door-0.3.stl
crkbd/stls/crkbd-case-bottom.stl
crkbd/stls/crkbd-case-top.stl
redox-case.scad
crkbd/crkbd-case-alt.scad
crkbd/crkbd-case-minimal.scad
crkbd/crkbd-case.scad
crkbd/crkbd-common.scad
crkbd/kle/crkbd-layout.scad
ergodox/ergodox-case.scad
ergodox/kle/ergodox-layout.scad
humla/humla-case.scad
humla/kle/hp-zbook.scad
humla/kle/hp-zenbook.scad
humla/kle/macbook-pro-2015.scad
misc/misc-parts.scad
not-so-minidox/kle/not-so-minidox-layout.scad
not-so-minidox/not-so-minidox-case.scad
redox-rev0-mod/redox-body-mod.scad
redox-rev0b/kle/redox-layout.scad
redox-rev0b/redox-case.scad

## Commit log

2018-03-17 Initial version of bolt-based tenting mounts
    [redox_body.scad]
2018-03-17 Tenting uses chamfer_extrude and computes offset from nut size. As printed for prototype
    [redox_body.scad]
2018-04-12 Add extra tent support, holes for mini-usb and microswitch
    [redox_body.scad]
2018-04-12 Add base STL
    [BottomR.stl, redox_body.scad]
2018-04-27 Add a small bracket to prevent micro-usb breakout mounting screw heads from hitting the micro-usb socket
    [redox_body.scad]
2018-04-29 Tweak micro-usb bracket
    [redox_body.scad]
2018-05-03 Add rubber mold for encasing bolt heads in oogoo
    [redox_body.scad]
2018-05-03 Add stls
    [Foot_Mold.stl, Micro_USB_Spacer.stl, Tented_BottomL.stl]
2018-05-30 Add case generated from scratch, plus tools
    [ergodox-case.scad, ergodox-layout.scad, keyboard-case.scad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]
2018-06-01 Tweaks to port positions
    [keyboard-case.scad, redox-case.scad]
2018-06-25 Improve oogoo foot molds
    [Foot_Mold.stl, redox-body-mod.scad]
2018-06-25 Add STLs for the new case
    [redox-case.scad, redox-rev0b-bottom.stl, redox-rev0b-hightop.stl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]
2019-01-25 Allow specifying the key position variable name.
    Handy if you want to load and compare multiple layouts.
    [ergodox-case.scad, ergodox-layout.scad, redox-case.scad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]
2019-01-25 Allow control over chamfering.
    [keyboard-case.scad]
2019-02-03 Allow override of keystem and switch body in preview.
    [keyboard-case.scad]
2019-02-03 Control chamfer_faces via simple boolean.
    [keyboard-case.scad]
2019-02-03 Slightly tweak standoff.
    [keyboard-case.scad]
2019-02-05 Allowing adjustable split height between top and bottom cases.
    [keyboard-case.scad]
2019-03-12 Remove bogus parameters.
    [keyboard-case.scad]
2019-03-12 Refine switch hole recesses.
    [keyboard-case.scad]
2019-03-12 Reorder functions
    [keyboard-case.scad]
2019-03-12 Sit breakout modules on z=0
    [keyboard-case.scad, redox-case.scad]
2019-03-21 Moving redox case files into their own subdirs.
    [BottomR.stl, Foot_Mold.stl, Micro_USB_Spacer.stl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]
2019-03-21 WIP: not-so-minidox. Needs improvement in case screws.
    [not-so-minidox-case.scad, not-so-minidox-layout.scad]
2019-03-21 Initial crkbd case design.
    [crkbd-case.scad, crkbd-layout.scad]
2019-03-25 Improve printability with removable cross supports.
    [crkbd-case.scad]
2019-03-25 Scale/position tweaks for better fit with pcb.
    [crkbd-case.scad, crkbd-layout.scad]
2019-03-25 Tweaks and add image of current corne case.
    [crkbd-case.scad]
2019-03-26 Correct mirror call in key_positions function.
    [keyboard-case.scad]
2019-04-19 Tweak connector positions and add stls.
    [crkbd-case-bottom.stl, crkbd-case-top.stl, crkbd-case.scad]
2019-06-07 Update svg offsets, latest openscad-nightly has different offsets during svg import.
    [crkbd-case.scad]
2019-06-18 Add a printable hard case, initial version.
    [crkbd-case-carrier-door-0.3.stl, crkbd-case-carrier.stl, crkbd-case.scad]
2019-06-22 Image of the carrying case.
2019-10-15 Add top_plate function
    [keyboard-case.scad]
2019-10-15 Allow a little customization over switch plate hole recesses.
    [keyboard-case.scad]
2019-10-17 More control over bottom case chamfer top/bottom and tent support lift.
    [keyboard-case.scad]
2019-11-28 Support foot molds on cap-head bolts.
    [misc-parts.scad]
2019-11-28 Alternative crkbd case design.
    This one has a top plate and bottom part of the case comes up the sides
    to a high-profile style. Support nrfmicro module for bluetooth, with bay
    for a lipo battery.
    [crkbd-case-alt.scad]
2020-02-06 Fix include paths that hadn't been updated.
    [ergodox-case.scad]
2020-07-13 Pull out some pieces common to all crkbd cases.
    [crkbd-case-alt.scad, crkbd-case.scad, crkbd-common.scad]
2020-07-13 STLs for basic alternate case.
    [crkbd-case-alt-bottom.stl, crkbd-case-alt-top.stl]
2020-07-13 First version of minimal case.
    [crkbd-case-minimal-bottom.stl, crkbd-case-minimal-top.stl, crkbd-case-minimal.scad]
2021-01-04 Window mounting hole position tweak
    [crkbd-common.scad]
2021-01-04 Increased tenting angle
    [crkbd-case-minimal.scad]
2021-01-07 Add small mounting plate for rotary encoder where TRRS jack normally goes.
    [crkbd-case-encoder-mount.scad, crkbd-case-encoder-mount.stl]
2021-03-10 Encoder mount tweak so it sits flusher
    [crkbd-case-encoder-mount.scad, crkbd-case-encoder-mount.stl]
2021-03-25 Minimal base, support minimal, flush and hi-pro versions
    [crkbd-case-minimal.scad]
2021-05-31 Alternate battery positions
    [crkbd-case-minimal.scad]
2023-01-22 Huma cases
    Basic bumper plus a "laptop adaptor"
    [hp-zenbook.scad, humla-case.scad]
2023-01-22 Add humla stls
    [humla-bumper-case.stl, humla-laptop-adaptor-case-bottom.stl]
2023-01-24 Correct lappy model
    [hp-zbook.scad, humla-case.scad]
2023-03-05 Simple humla carrying case to fit over the bumper case
    [humla-case.scad]
2023-04-22 Humla laptop adaptor for 2015 macbook pro
    [humla-bumper-case.stl, humla-case.scad, humla-laptop-adaptor-case-bottom.stl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]
